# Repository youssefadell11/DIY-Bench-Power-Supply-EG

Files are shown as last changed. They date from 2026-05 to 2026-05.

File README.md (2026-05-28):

# ⚡ Open-Source Bench Power Supply

An open-source, DIY bench power supply designed for precision voltage and current regulation. Repurposing an old PC ATX power supply, this build leverages the **XL4015 5A DC-DC Step-Down Buck Module** for robust regulation and integrates a **DSN-VC288** dual display for real-time voltage and current monitoring. 

Whether you are powering up custom PCB layouts, tuning DC motor control circuits, or running standalone microcontrollers, this compact unit provides the stable, adjustable power required for reliable testing and development.

---

## 📸 Project Media

### Overview

<p align="center">
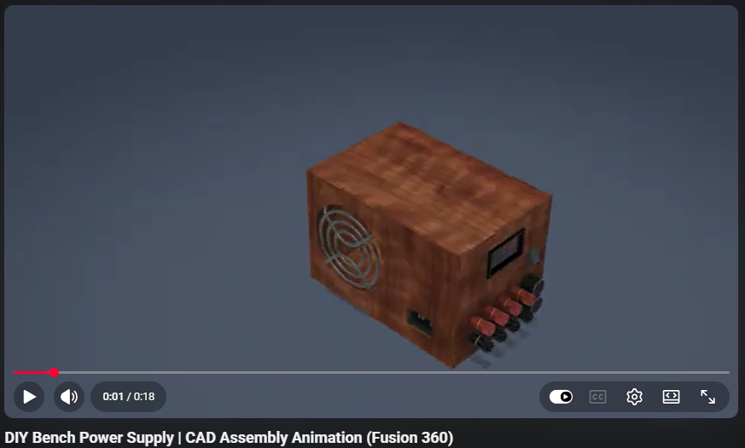
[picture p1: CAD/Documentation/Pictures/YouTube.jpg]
  
</p>

<p align="center">
  ▶️ <a href="https://www.youtube.com/watch?v=nhQbDIVF7So"><b>Watch the Assembly & Demonstration on YouTube</b></a>
</p>

---
### 3D Renderings
Here is a look at the mechanical design and assembly.

<p align="center">
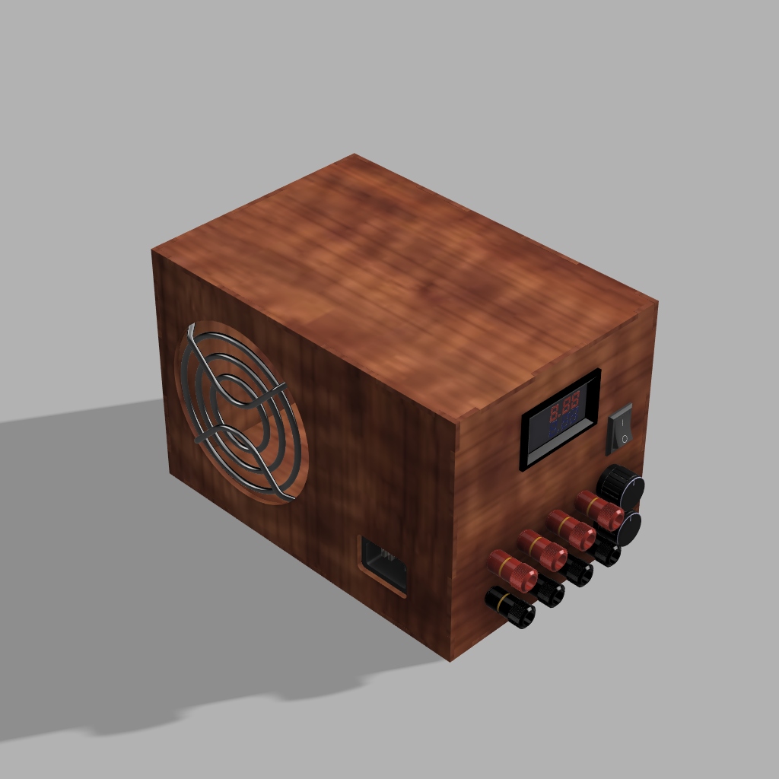
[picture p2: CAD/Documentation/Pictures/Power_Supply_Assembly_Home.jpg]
Home View
  
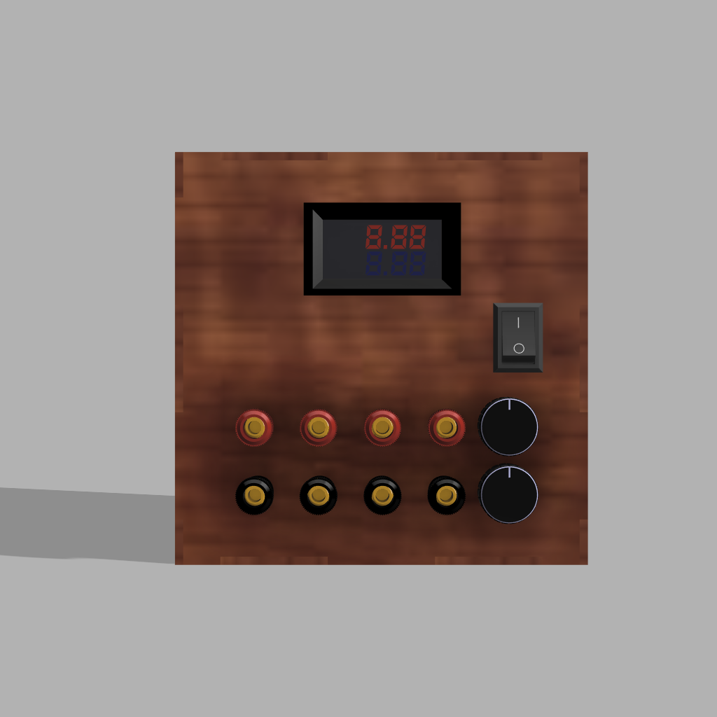
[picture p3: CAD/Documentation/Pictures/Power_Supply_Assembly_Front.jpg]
Front View
  
</p>
<p align="center">
  <em>(Fig1: Home view. Fig2: Front -Panel Interface-)</em>
</p>

---

## ✨ Features
* **Upcycled Core:** Gives a second life to a standard desktop PC power supply.
* **Precision Regulation:** Utilizes the XL4015 buck converter for clean, adjustable DC output (up to 5A).
* **Integrated Telemetry:** Front-panel DSN-VC288 meter provides instant, clear feedback on voltage and current draw.
* **Modular CAD Design:** Fully modeled enclosure and components. The geometry is clean and easily modified to fit different hardware footprints.
* **Standard Interfaces:** Uses 10K potentiometers for fine-tuning and standard red/black banana plugs for universal lead compatibility.

---

## 🛠️ CAD & 3D Modeling

The physical enclosure and component mountings were meticulously modeled. Native Autodesk Fusion 360 project files are included, making it easy to edit features, adjust tolerances, or remix the design for your specific PC power supply dimensions.

🔗 **[View and Download the Native Fusion 360 Model Here](https://a360.co/4vcgt6b)**

Standardized `.step` files are also provided for all individual parts and the main assembly for use in other CAD environments.

---

## 📂 Repository Structure

```text
├── CAD/
│   ├── Documentation/
│   │   ├── Pictures
│   │   └── Videos
│   ├── DXF
│   ├── Fusion
│   ├── STEP/
│   │   ├── Assembly
│   │   └── Parts
├── Hardware/
│   ├── BOM
│   ├── Documentation/
│   │   ├── Pictures
│   │   └── Videos
│   ├── PDFs/
│   │   ├── Circuit
│   │   └── DNS_VC288
└── README.md
```

---
## ⚙️ Hardware & Bill of Materials (BOM)
A complete breakdown of the required hardware, wiring diagrams, and datasheets can be found in the `Hardware/` directory.

### Core Components List:
| Component | Quantity | Notes |
| --- | --- | --- |
| PC ATX Power Supply | 1 | Source of DC power, upcycled from old PC |
| XL4015 DC-DC Step-Down Module | 1 | For voltage regulation |
| DSN-VC288 Dual Display | 1 | For real-time voltage and current monitoring |
| 10K Potentiometer | 2 | For adjusting voltage and current limits |
| Banana Plugs (Red/Black) | 8 | For output connections |
| Enclosure | 1 | For housing the components |
| Rocker Switch | 1 | For power control |

For detailed sourcing, refer to the 🔗 **[BOM.xlsx](https://github.com/youssefadell11/DIY-Bench-Power-Supply-EG/tree/main/Hardware/BOM)**

---
## 📝 License & Open Source
This project is open-source. You are free to download, modify, and integrate this design into your own electronic workspaces. Contributions, forks, and improvements to the enclosure or wiring schematics are welcome!

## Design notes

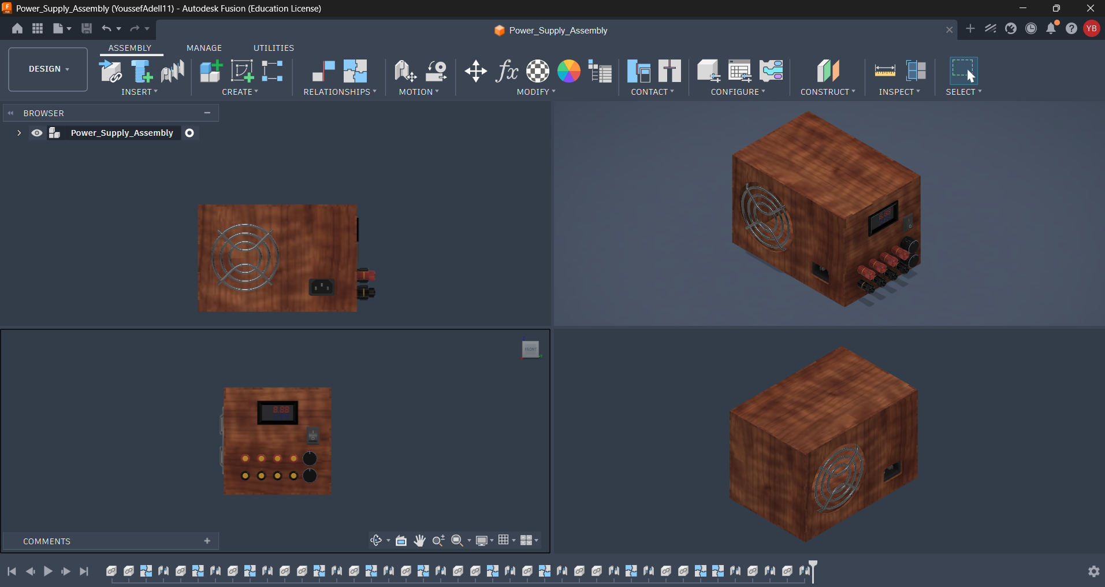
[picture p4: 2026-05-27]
CAD/Documentation/Pictures/Fusion360.jpg

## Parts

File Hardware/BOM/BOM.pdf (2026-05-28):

# Open-Source Bench Power Supply

Component | Quantity | Makers Link (Hyperlink) | Price | Total
PC ATX Power Supply | 1 | Makers Link (https://makerselectronics.com/product/acbel-36200087-pc8061-psu-power-supply-180w-used-like-new/) | 900 | 900
XL4015 DC-DC Step-Down Module | 1 | Makers Link (https://makerselectronics.com/product/xl4015-adjustable-dc-dc-step-down-module-with-display-5a-75w/) | 120 | 120
DSN-VC288 Dual Display | 1 | Makers Link (https://makerselectronics.com/product/dc-0-100v-10a-digital-voltmeter-and/) | 100 | 100
10K Potentiometer | 3 | Makers Link (https://makerselectronics.com/product/metal-potentiometer-10k%cf%89-3-pin/) | 5.5 | 16.5
Potentiometer Knob (6×13×17) mm | 2 | Makers Link (https://makerselectronics.com/product/potentiometer-knob-cap-for-6mm-shaft/) | 10 | 20
Banana Plugs (Red/Black) | 8 | Makers Link (https://makerselectronics.com/product/banana-plug-female-30a-4mm/) | 16 | 128
Rocker Switch | 2 | Makers Link (https://makerselectronics.com/product/kcd1-11-on-off-black-switch-2-pins/) | 2.5 | 5
AC Power Socket 3 Pin Male Plug Connector | 1 | Makers Link (https://makerselectronics.com/product/socket-3-pin-male-connector-10a-250v/) | 9 | 9
Power Cable Male | 1 | Makers Link (https://makerselectronics.com/product/grey-3-core-power-cable-10a-1-2meter/) | 35 | 35
Power Resistor 7W 0.1Ω | 1 | Makers Link (https://makerselectronics.com/product/power-resistor-7w-0-1%cf%89/) | 5 | 5
Fuse Holder Wire 250V 10A R3-11 | 1 | Makers Link (https://makerselectronics.com/product/fuse-holder-wire-250v-10a/) Makers Link (https://makerselectronics.com/product/glass-fuse-3-15a-250v-t5x20mm/) | 9 | 9
Glass Fuse 3.15A 250V | 4 | | 0.75 | 3
Enclosure | 1 | | 100 | 100
Total | | | | 1450.5

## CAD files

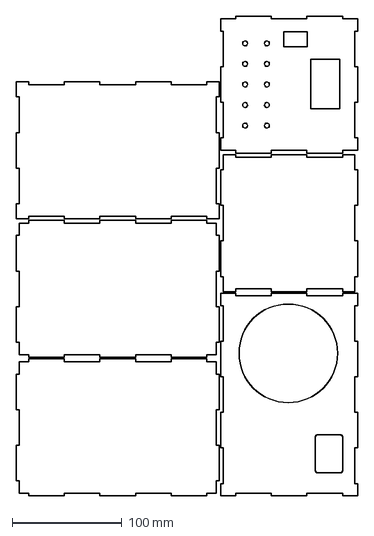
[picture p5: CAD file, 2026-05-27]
CAD/DXF/Power_Supply.dxf
311.5 x 438.0 mm

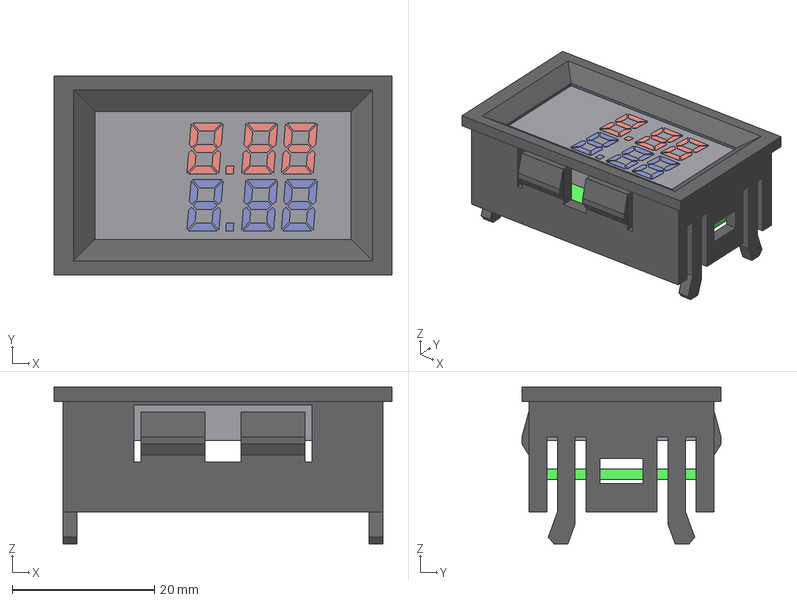
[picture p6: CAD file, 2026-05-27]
CAD/STEP/Parts/Volt_Current_Meter_DSNVC288.step
47.5 x 28.0 x 22.0 mm

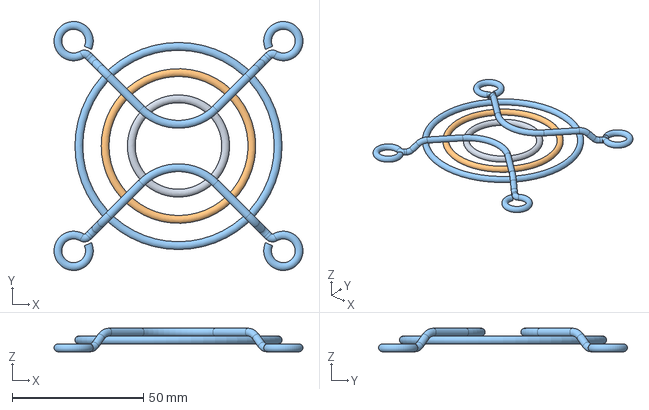
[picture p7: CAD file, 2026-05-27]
CAD/STEP/Parts/Fan_Protection_Grill.step
95.0 x 95.0 x 9.00 mm

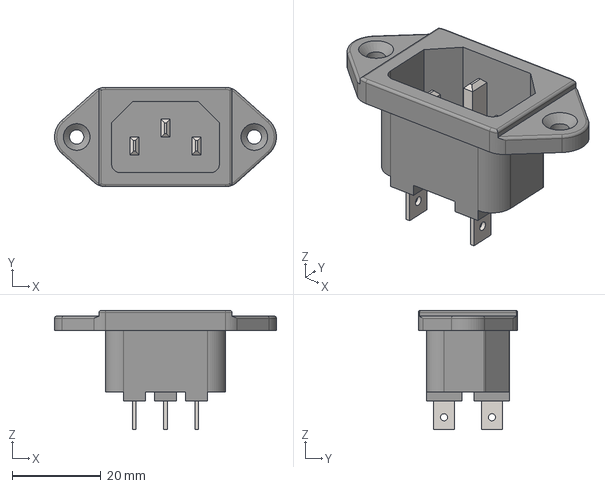
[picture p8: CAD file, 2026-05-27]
CAD/STEP/Parts/Power_Connector.step
50.0 x 22.4 x 26.9 mm

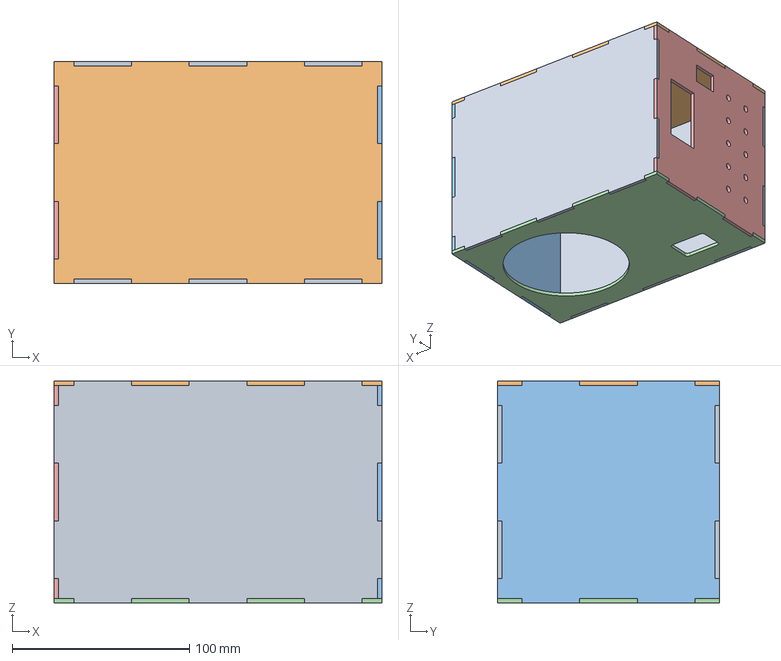
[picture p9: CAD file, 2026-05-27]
CAD/STEP/Parts/Power_Supply_Body.step
185.0 x 125.0 x 125.0 mm

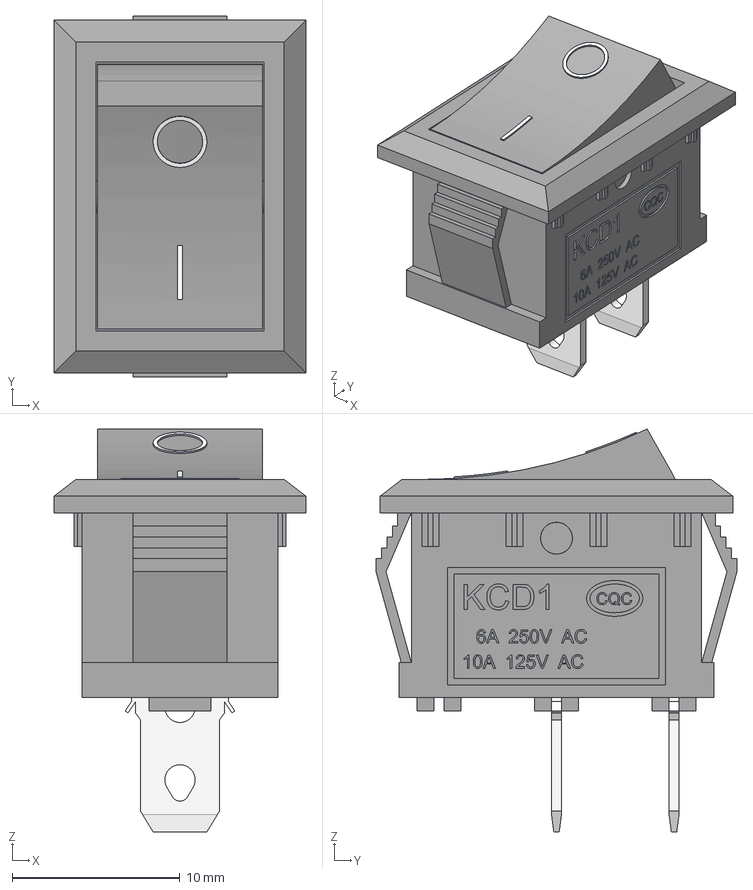
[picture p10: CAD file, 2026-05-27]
CAD/STEP/Parts/Rocker_Switch.step
15.0 x 21.5 x 24.0 mm

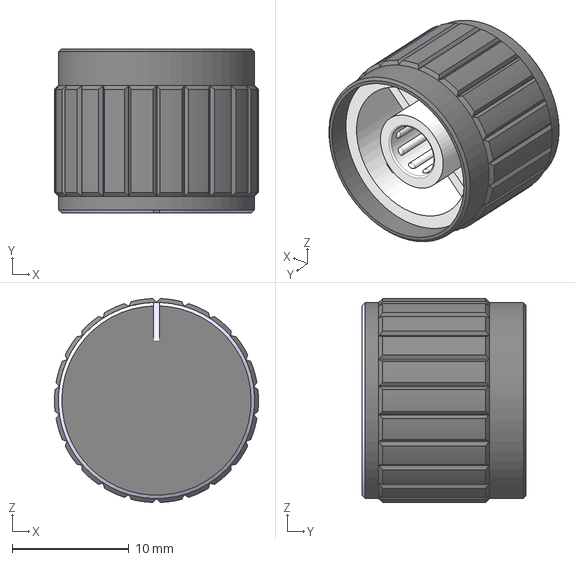
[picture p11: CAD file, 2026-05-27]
CAD/STEP/Parts/Potentiometre_Knob.step
17.5 x 14.1 x 17.5 mm

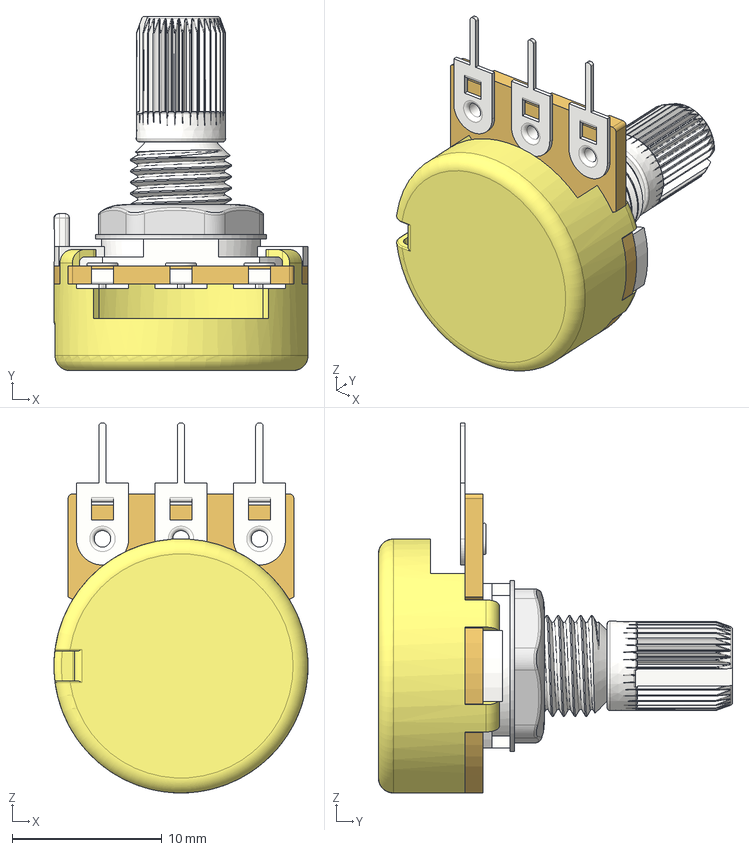
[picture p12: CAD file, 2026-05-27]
CAD/STEP/Parts/Potentiometre_10K.step
17.0 x 23.7 x 24.8 mm

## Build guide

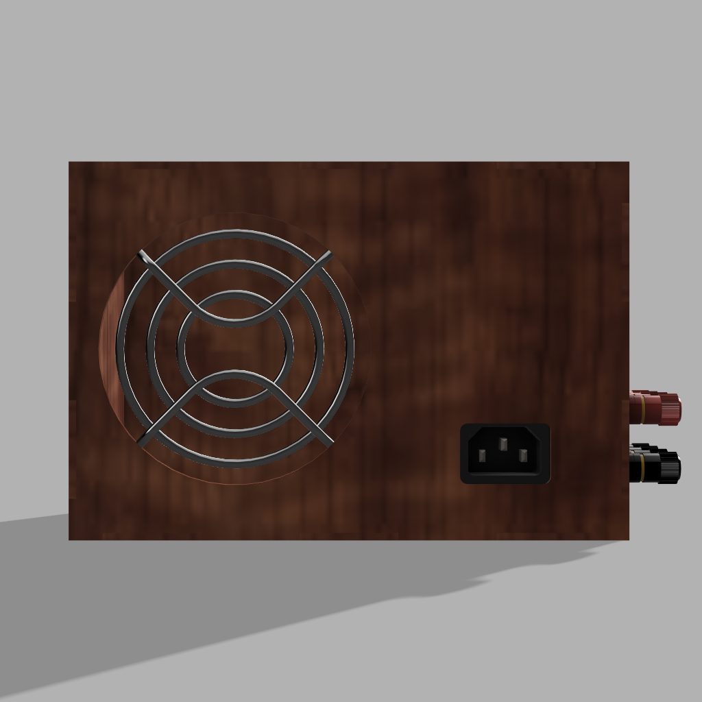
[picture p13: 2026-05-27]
CAD/Documentation/Pictures/Power_Supply_Assembly_Left.jpg
